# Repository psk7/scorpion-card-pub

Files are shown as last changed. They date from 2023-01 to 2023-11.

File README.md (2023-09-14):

## Контроллер периферии для ретро-компьютера Scorpion ZS-256

## Ревизия B:

Подключается к разъему периферии платы компьютера. Позволяет использовать USB клавиатуры, мыши, джойстики, геймпады.



## Ревизия С:
                 
Автономный контроллер USB клавиатуры и геймпада. Не привязан к разъему Scorpion и может
быть использован с любым Spectrum совместимым компьютером, использующим стандартную ZX клавиатуру, но
не имеет поддержки Kempston Mouse и возможностей, обеспечиваемых периферийным разъемом ZS-Scorpion за исключением
клавиатуры и Kempston джойстика.



## Уже реализовано:
- USB-хост: поддержка клавиатур, HID мышей, HID джойстиков/геймпадов, USB хабов
- USB-устройство: подключается к PC, возможно взаимодействие PC со Spectrum
- Безвейтовая ZX-клавиатура с произвольными раскладками, настраиваемыми с PC 
- Reset, Magic с клавиатуры
- Настраиваемые раскладки USB джойстика/геймпада, возможно задействование до 16 кнопок 
- Регенерация синхросмеси. Никаких больше перемычек/разрезов на плате. PAL кодер теперь дает нормальный цветной сигнал
- С доп. платой (в слот шины) USB мышь превращается в Kempston mouse
- Транзитом передает на гребенки: RGB сигнал (с выбором джампером оригинальная/регенерированная синхросмесь), стерео-аудио, моно-аудио, оригинальный видео сигнал, магнитофонный вход/выход, RS-232
- Единая точка подключения питания
- Подключение внешнего джойстика (от Spectrum)
- Настраиваемое отображение кнопок USB джойстика на кнопки ZX клавиатуры/Kempston Joystick
- Управление/индикация на клавиатуре турбой через двухпиновую колодку скорпиона
- Захват centronix в передача на PC
- Проигрыватель tap/tzx с PC через USB порт в Спектрум (`LOAD ""`)
- Транзитная передача с RS232 Скорпиона 
- Поддержка нескольких джойстиков/геймпадов

### Планируется:
- Настройки контроллера (раскладки, мышь, джойстик) через доп. плату нативным приложением для скорпиона

### Недостатки: :smile:
- Нет поддержки PS/2 мышей и клавиатур

## Ревизия А: (Устаревшая)

ВНИМАНИЕ!!! Эта ревизия НЕ РЕКОМЕНДУЕТСЯ К ИЗГОТОВЛЕНИЮ. К сожалению, при проектировании был выбран микроконтроллер не позволяющий реализовать все желаемое по причине нехватки ОЗУ. Готовится к публикации ревизия B, в которой эта проблема устранена.

Файлы для производства удалены из репозитория.

## Содержимое репозитория:
### revB
- cpld - Прошивки микросхем EPM3064
- gerbers - Файлы для производства плат

### revC
- kbd - Прошивка клавиатурной матрицы
- kicad - Проект плат
- atmega - Прошивка управляющего контроллера

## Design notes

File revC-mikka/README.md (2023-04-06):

## Специальная редакция контроллера клавиатуры ревизии C для Mikka_A

Ревизия C не предполагает поддержки мыши. Однако, по просьбе Mikka_A такая поддержка была добавлена.

Для соединения с платой портов мыши был позаимствован сервисный разъем для программирования микроконтроллера. 

В этой ревизии в FUSE установлен бит RSTDISBL, что исключат возможность программирования
микроконтроллера в устройстве. Программирование возможно только в высоковольтном параллельном режиме.

Также, полностью переработан подход к соответствию кнопок PC клавиатуры и ZX клавиатуры.

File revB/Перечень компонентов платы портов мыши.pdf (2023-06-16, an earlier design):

Номер | Корпус | Кол-во | Номинал | Примечание
C1 | C_0805_2012Metric | 1 10nF
C2 | C_Radial_D6.3mm_ H11.0mm_P2.50mm | 1 100uF
C3,C6,C4,C5 | C_0805_2012Metric | 4 0.1uF
J1 | PinHeader_2x05_P2.54mm | 1 | | JTAG
J2 | PinHeader_1x02_P2.54mm | 1 | | Не устанавливать
J3 | IDC-Header_2x04_P2.54mm | 1 EXT | | К контроллеру
R2,R1 | R_0805_2012Metric | 2 10k | | R1 можно не устанавливать
R3 | R_0805_2012Metric | 1 0
U1 | TQFP-44_10x10mm_P0.8mm | 1 EPM3064
U2 | SOT-89-3 | 1 L78L33

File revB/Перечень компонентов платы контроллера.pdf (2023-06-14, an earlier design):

Номер | Корпус | Кол-во | Номинал | Примечание
C13 | CP_Elec_6.3x7.7 | 1 220uF | | Любой подходящий SMD электролит или SMD тантал емкостью 200-1000мкф
C16 | Radial_D6.3mm_H11.0mm_P2.50m m | 1 200uF | | Любой подходящий выводной емкостью 200-1000мкф
C18,C4,C12 | C_0805_2012Metric | 3 4.7uF
C2,C1,C34,C33 | C_0805_2012Metric | 4 10p
C23 | C_0805_2012Metric | 1 10uF
C31,C6,C25,C24 | CP_EIA-3528-12_Kemet-T | 4 100uF
C35 | C_0805_2012Metric | 1 1uF
C36 | C_0805_2012Metric | 1 - | | Не устанавливать
C5,C11,C15,C21, C14,C10,C17, C26,C30,C3,C9,C 7,C8,C19 | C_0805_2012Metric | 14 0.1uF
D1 | LED_0805_2012Metric | 1
J1 | usb_mini | 1
J10,J5 | PinHeader_1x04_P2.54mm | 2
J11 | IDC-Header_2x04_P2.54mm | 1
J13 | PinHeader_2x03_P2.54mm | 1
J14 | PinHeader_1x02_P2.54mm | 1
J15 | PinHeader_2x05_P2.54mm | 1
J16 | ATX-4x4 | 1
J18 | PinHeader_1x04_P2.54mm | 1
J2 | PinHeader_1x03_P2.54mm | 1
J20 | PinHeader_1x02_P2.54mm | 1
J21 | PinHeader_1x02_P2.54mm | 1
J3 | PinHeader_2x05_P2.54mm | 1
J4,J7,J6 | PinHeader_1x02_P2.54mm | 3
J8 | PinHeader_1x07_P2.54mm | 1
J9 | PinHeader_1x03_P2.54mm | 1
R11 | R_0805_2012Metric | 1 1K
R13 | R_0805_2012Metric | 1 0
R14 | R_0805_2012Metric | 1 2k
R2,R1 | R_0805_2012Metric | 2 33
R3 | R_0805_2012Metric | 1 1k5
R5 | R_0805_2012Metric | 1 10k
R7 | R_0805_2012Metric | 1 1k
R8 | R_0805_2012Metric | 1 1k2
R9 | R_0805_2012Metric | 1 250
RN3,RN2,RN1 | RESCAF80P320X160X60-8N | 3 4x1k2
U1 | LQFP-64_10x10mm_P0.5mm | 1 STM32F103R8
U10 | SOT-223-3_TabPin2 | 1 LD1117S33TR
U11 | SOT-363_SC-70-6 | 1 TS5A3159DCK
U2 | TQFP-44_10x10mm_P0.8mm | 1 EPM3064
U3 | LQFP-32_5x5mm_P0.5mm | 1 MAX3421EEHJ+T
U4 | TSOP-6_1.65x3.05mm_P0.95mm | 1 IP4220CZ6
U5 | SOIC-8_3.9x4.9mm_P1.27mm | 1 25LC256T
U9 | SOT65P210X110-6N | 1 SMF05CT1G
Y2,Y1 | SMD_3225-4Pin_3.2x2.5mm | 2 12MHz

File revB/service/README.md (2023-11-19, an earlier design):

Программа сервисного обслуживания контроллера 

- Редактирование пользовательских раскладок клавиатуры
- Проигрыватель образов ленты TAP/TZX
- Резервное копирование/восстановление/сброс настроек контроллера
- Обновление встроенного ПО контроллера (firmware)

Версии
- SFNET-1 - Начальная версия
- SFNET-2 - Исправлены некоторые ошибки, возникающие при записи макроса

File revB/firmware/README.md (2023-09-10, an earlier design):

 - fw-1.bin, fw-1.hex - Первоначальная версия (10.09.2023)

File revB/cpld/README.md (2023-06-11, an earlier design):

- epm3064-main - Прошивка микросхемы EPM3064 контроллера клавиатуры
- epm3064-ext - Прошивка микросхемы EPM3064 дополнительной платы портов Kempston мыши

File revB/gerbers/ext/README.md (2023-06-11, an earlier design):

Производственные файлы для дополнительной платы портов Kempston мыши

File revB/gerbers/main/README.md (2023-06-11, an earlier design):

Производственные файлы для основной платы контроллера



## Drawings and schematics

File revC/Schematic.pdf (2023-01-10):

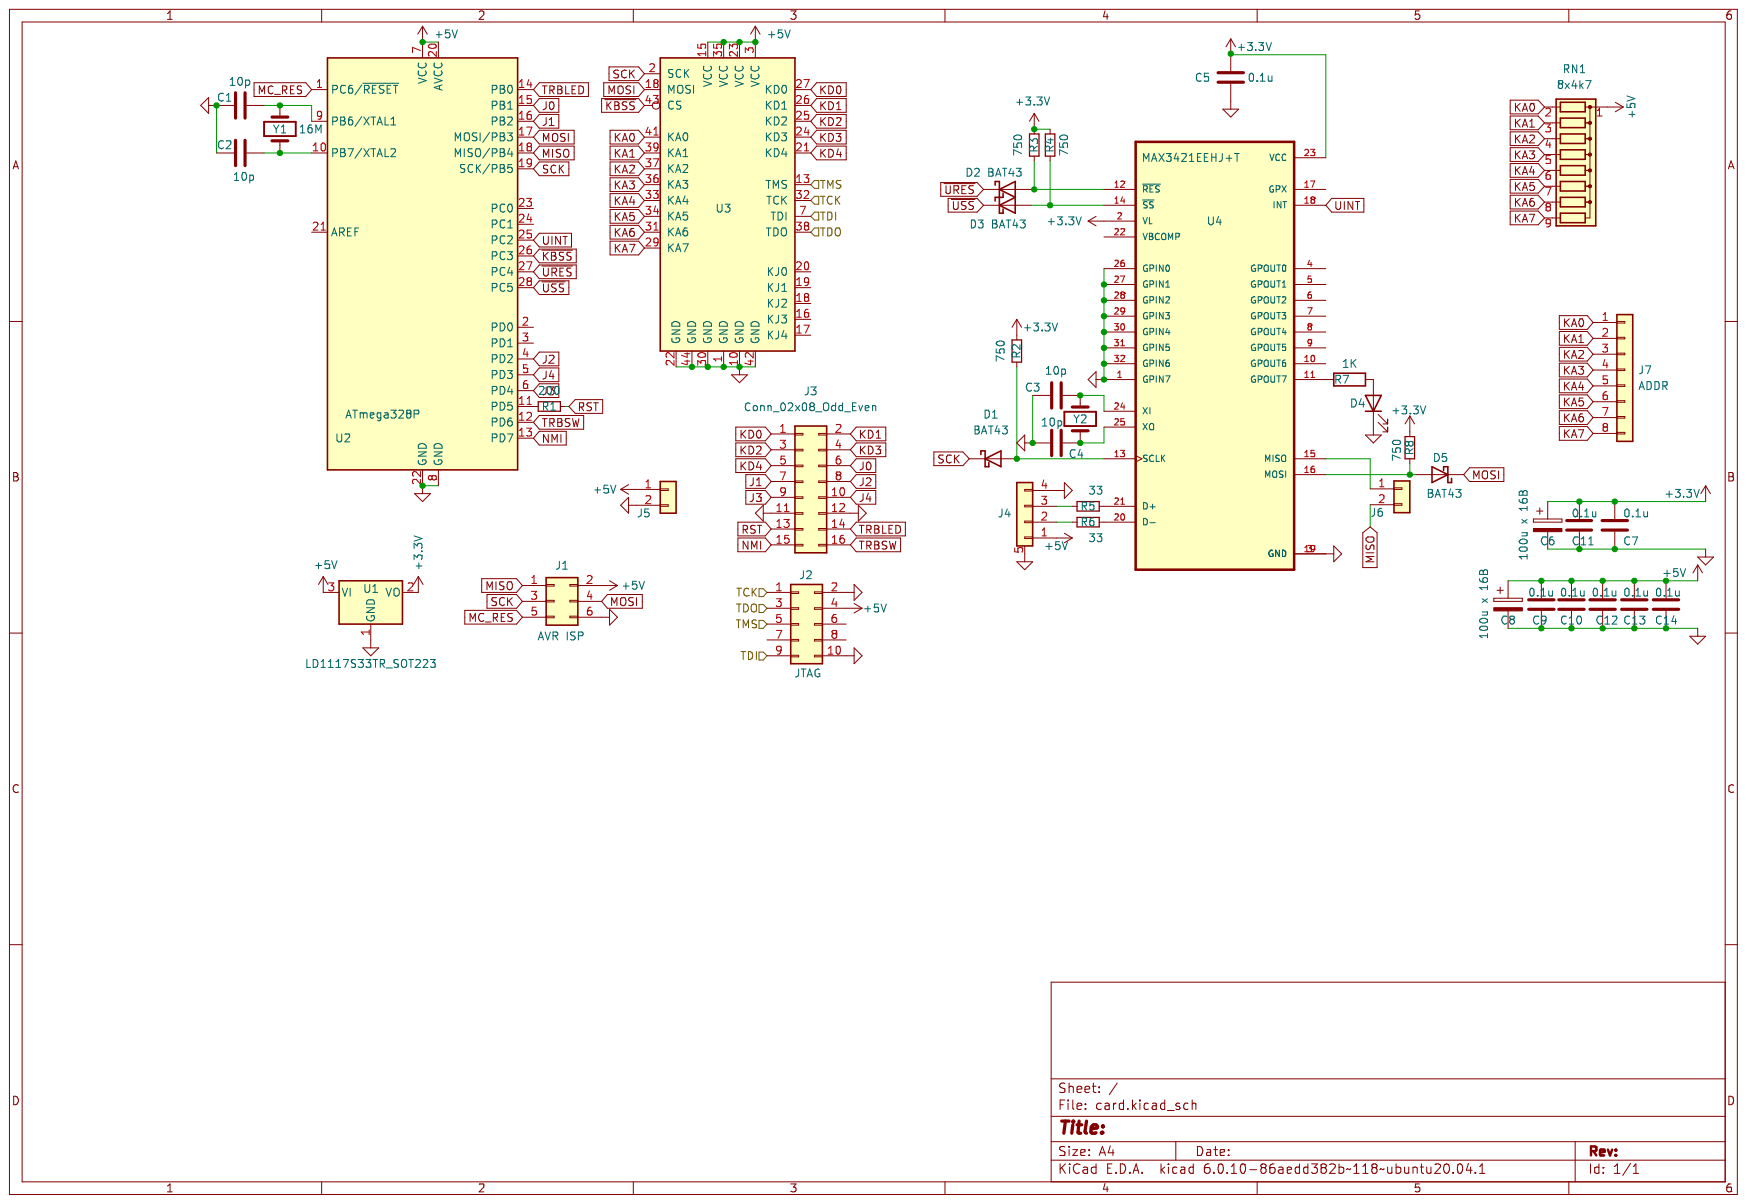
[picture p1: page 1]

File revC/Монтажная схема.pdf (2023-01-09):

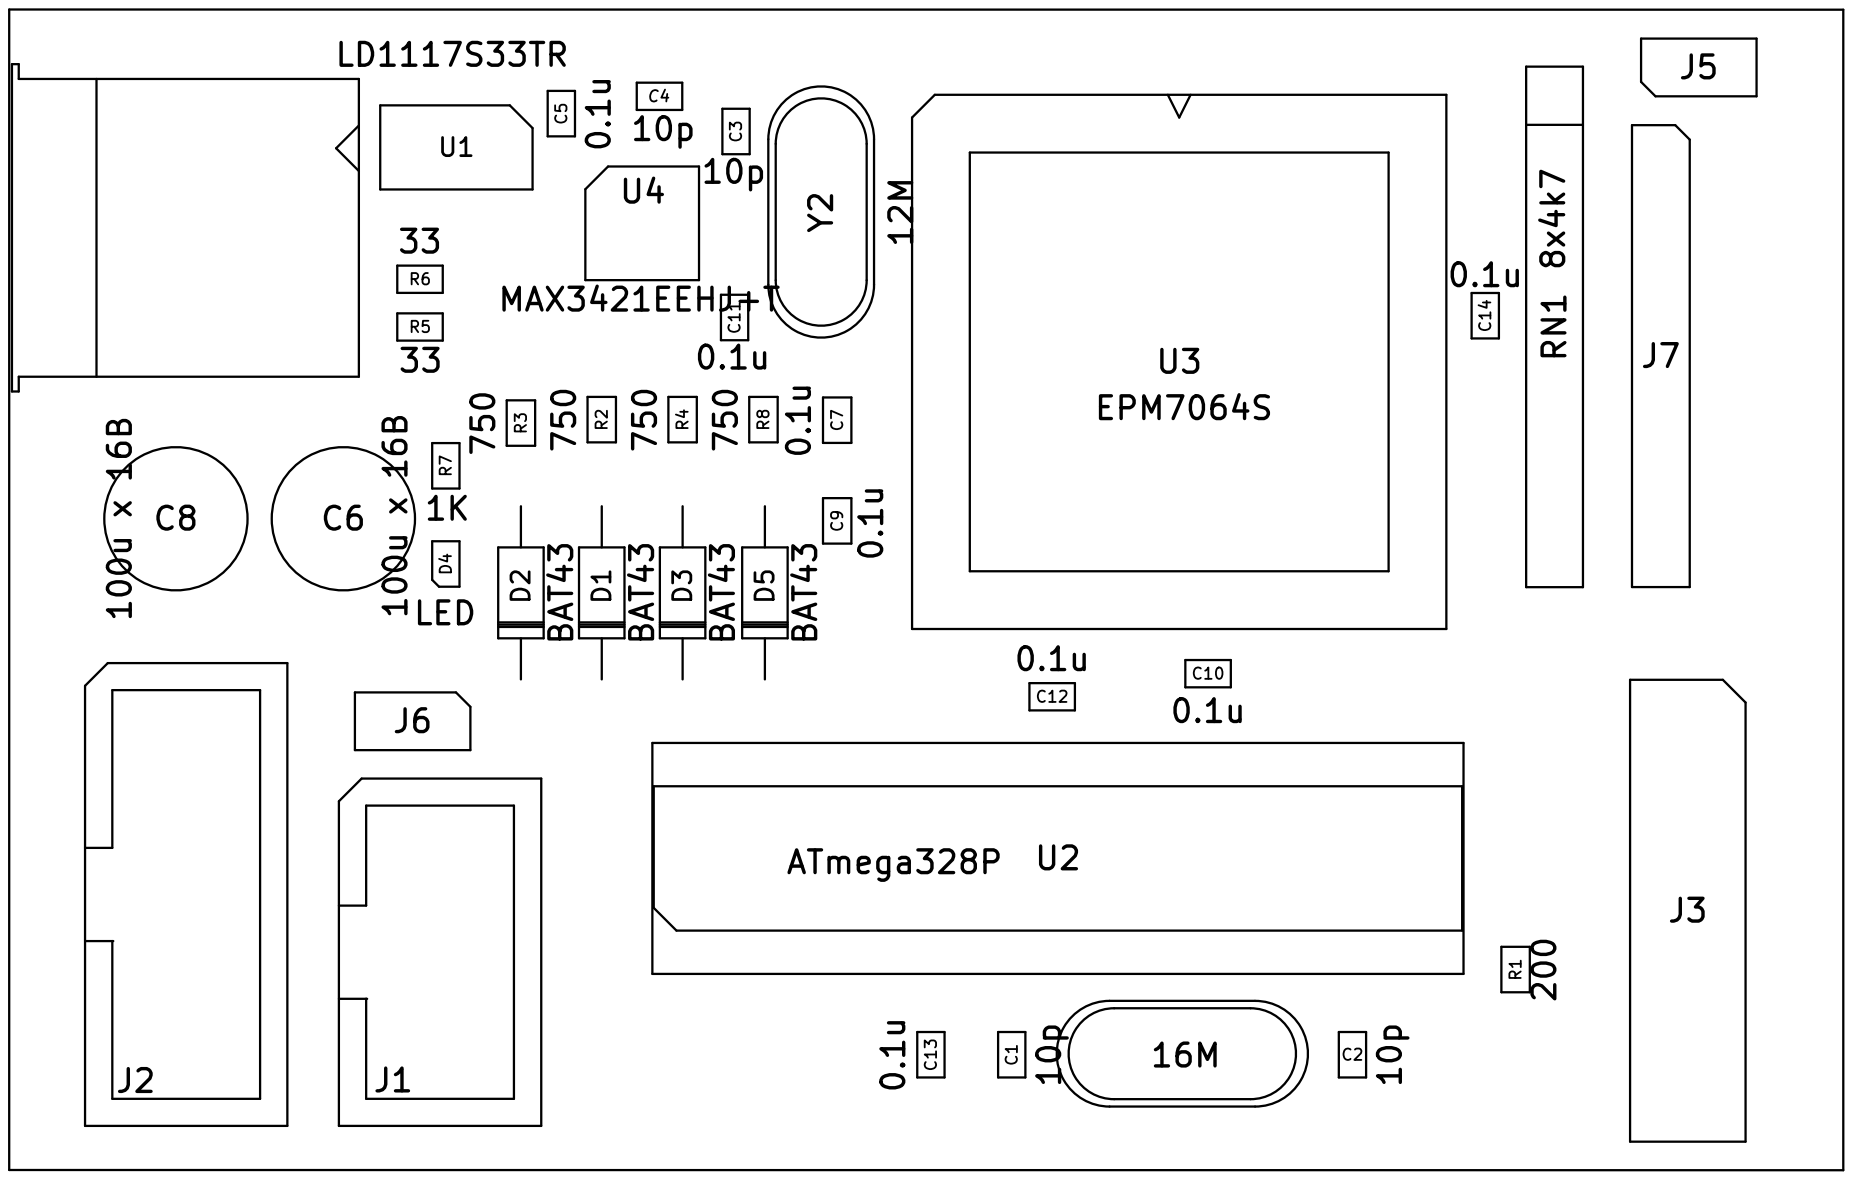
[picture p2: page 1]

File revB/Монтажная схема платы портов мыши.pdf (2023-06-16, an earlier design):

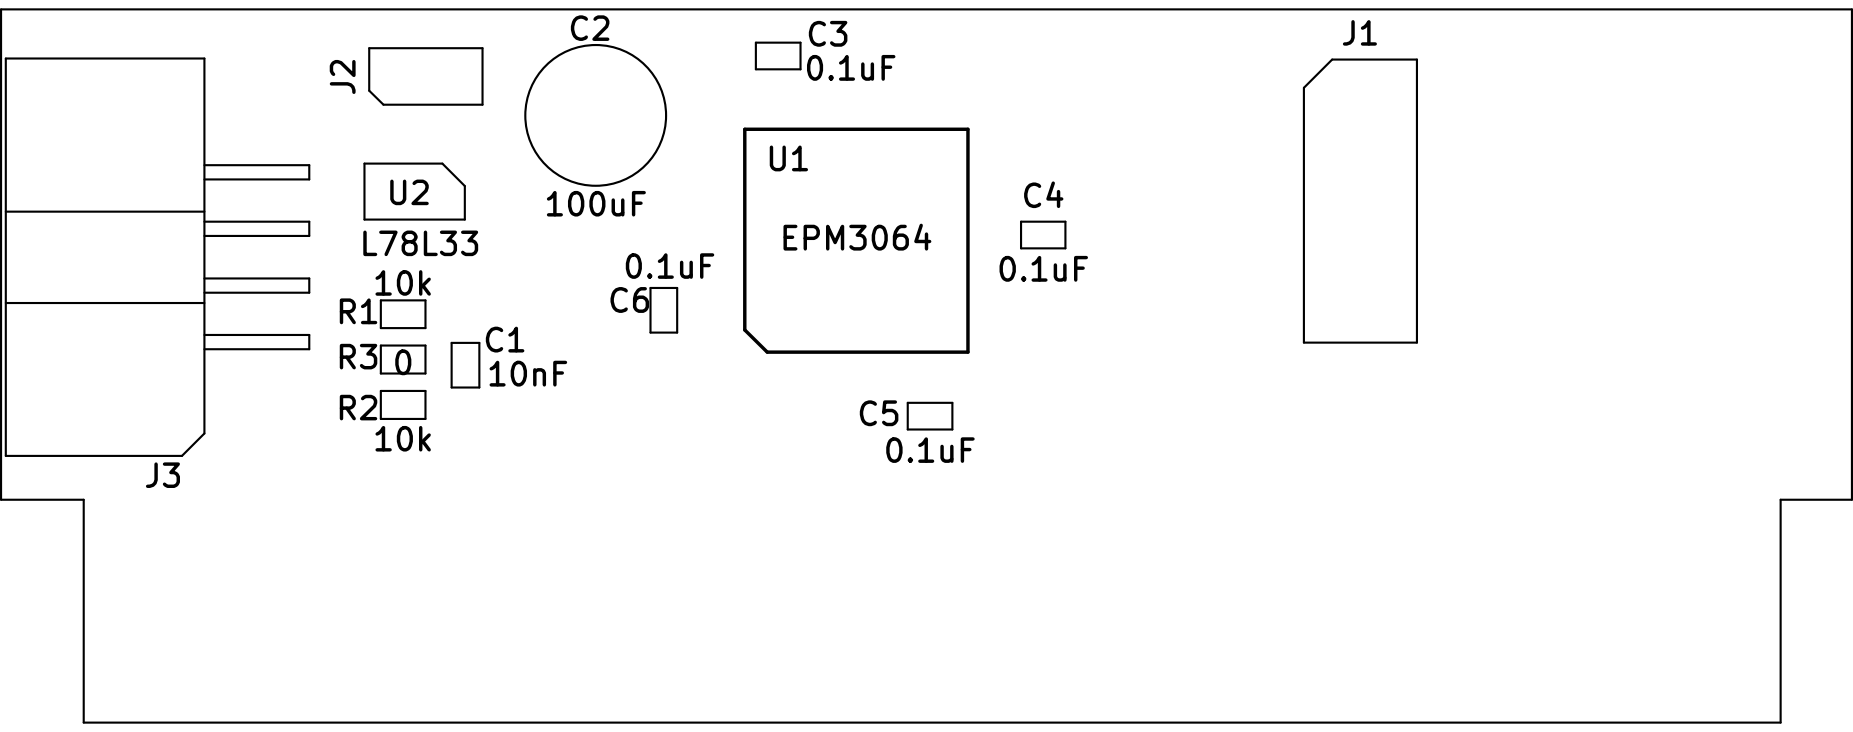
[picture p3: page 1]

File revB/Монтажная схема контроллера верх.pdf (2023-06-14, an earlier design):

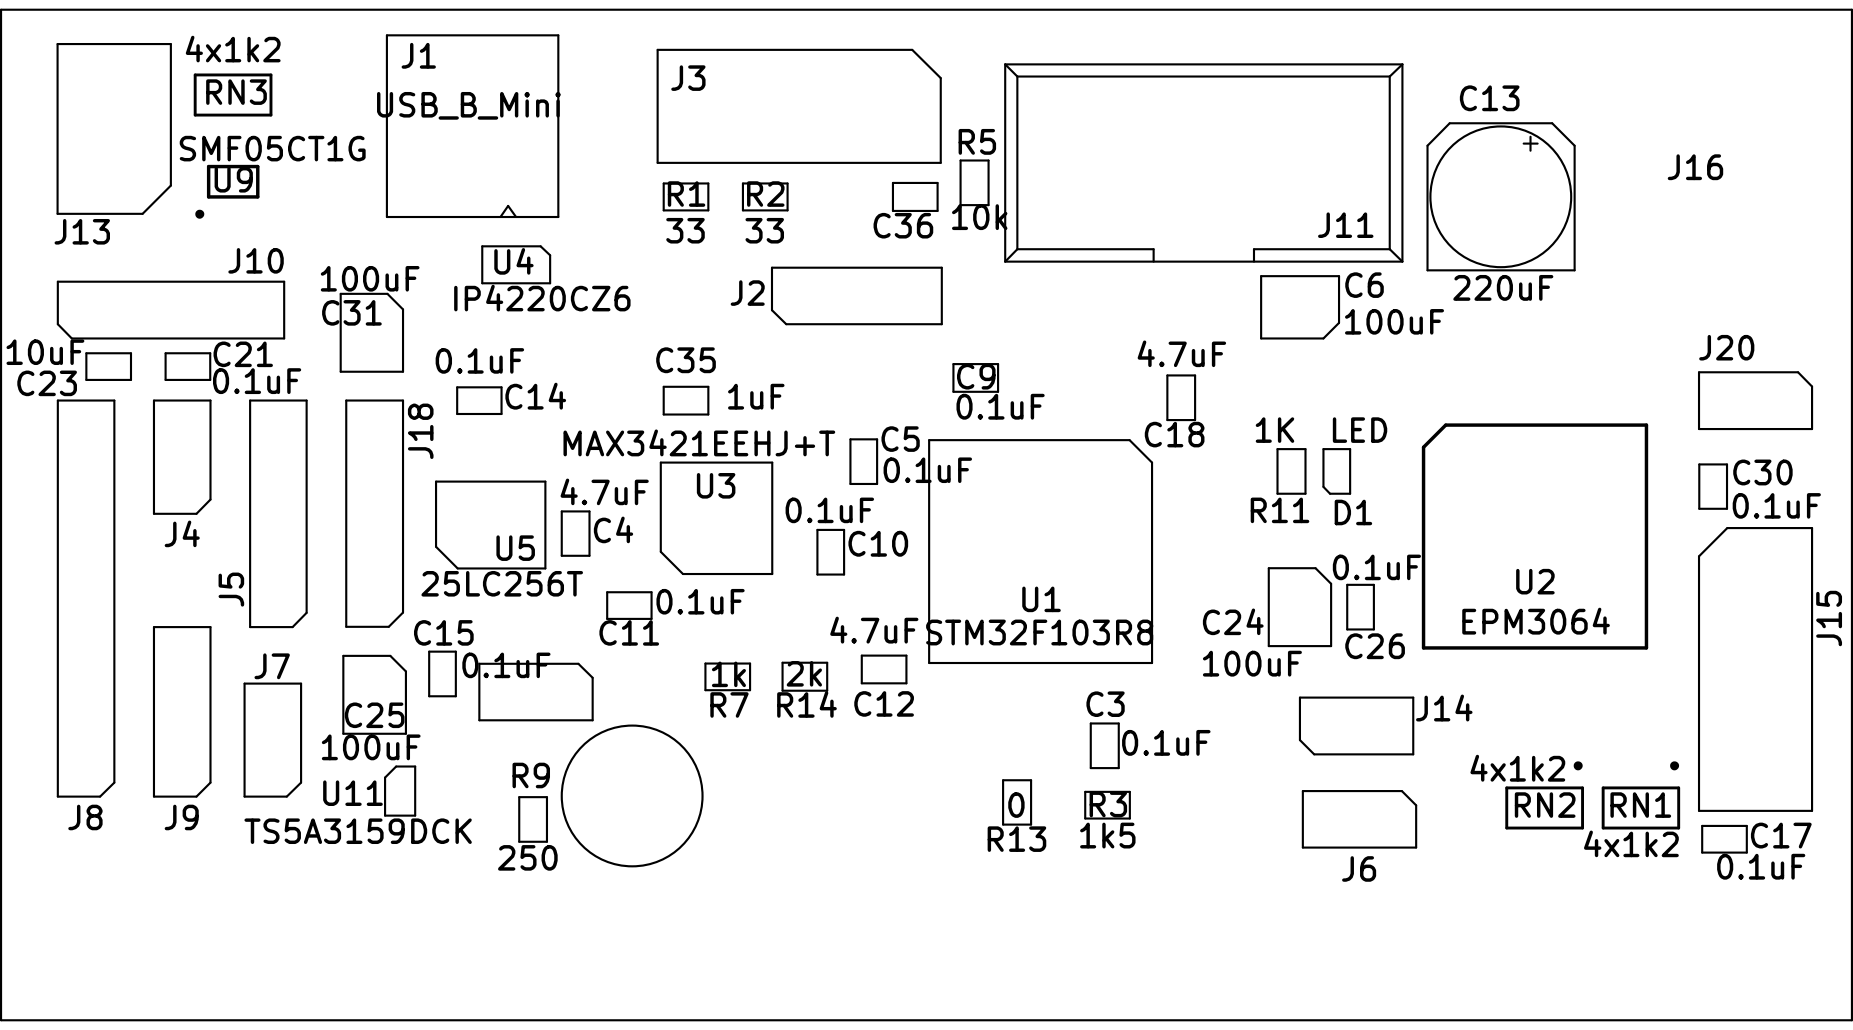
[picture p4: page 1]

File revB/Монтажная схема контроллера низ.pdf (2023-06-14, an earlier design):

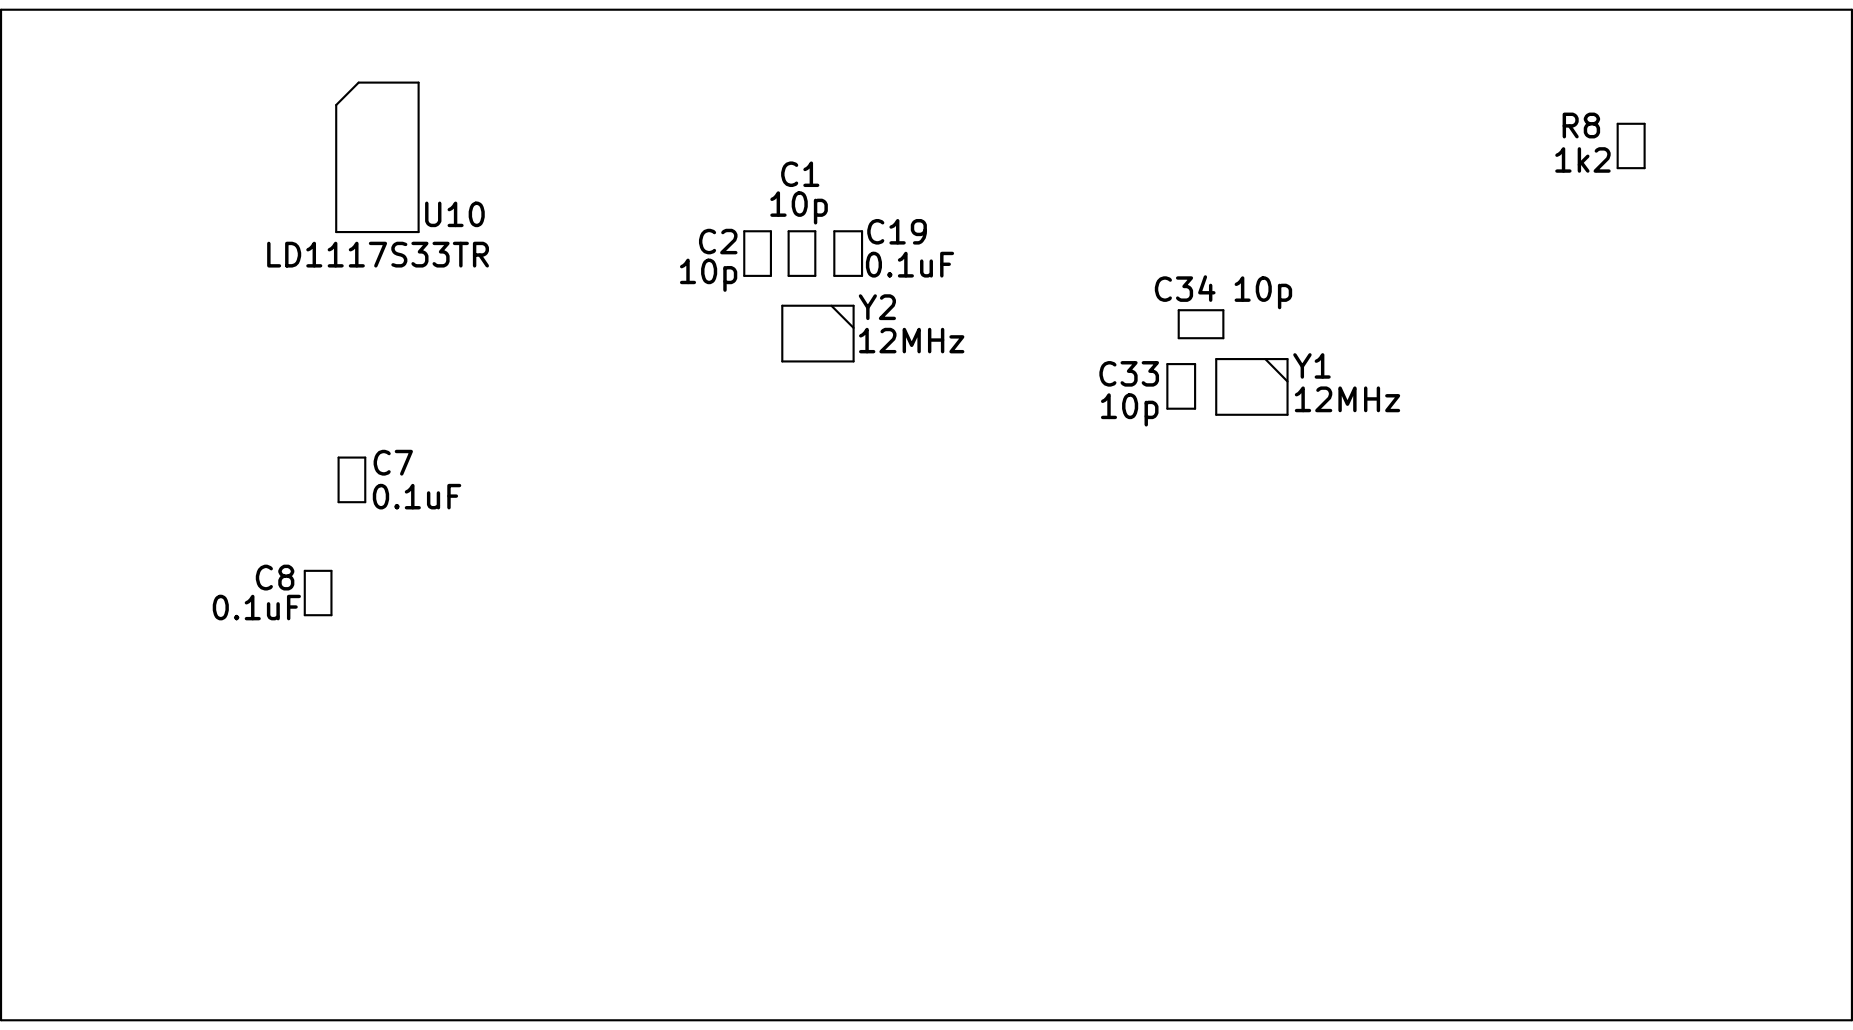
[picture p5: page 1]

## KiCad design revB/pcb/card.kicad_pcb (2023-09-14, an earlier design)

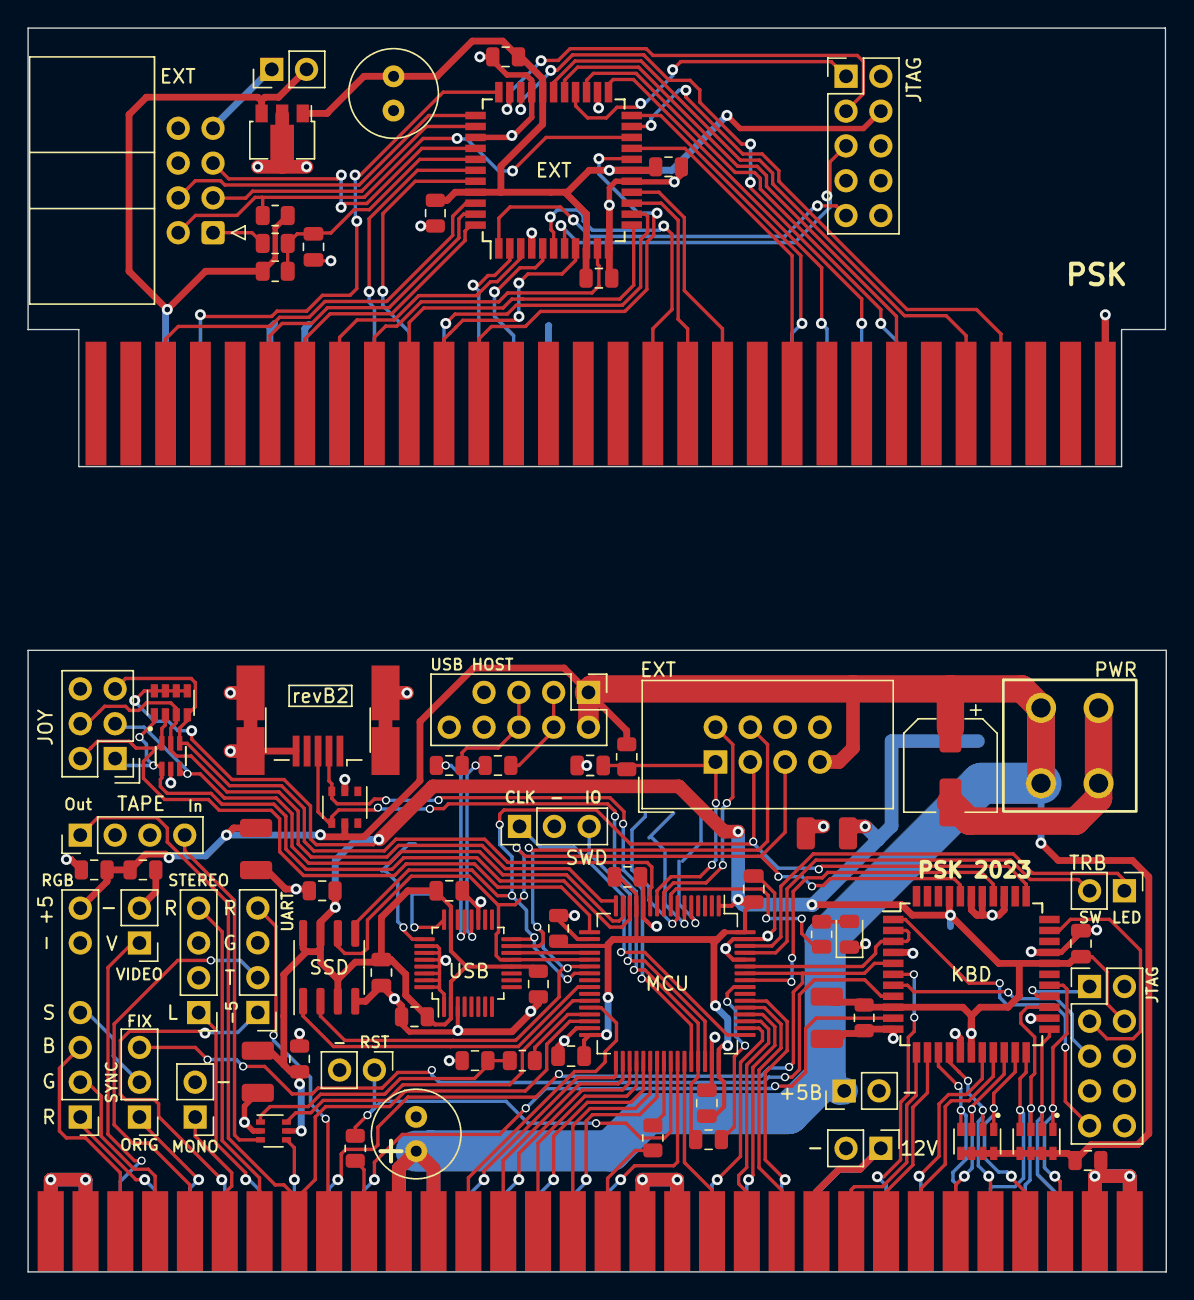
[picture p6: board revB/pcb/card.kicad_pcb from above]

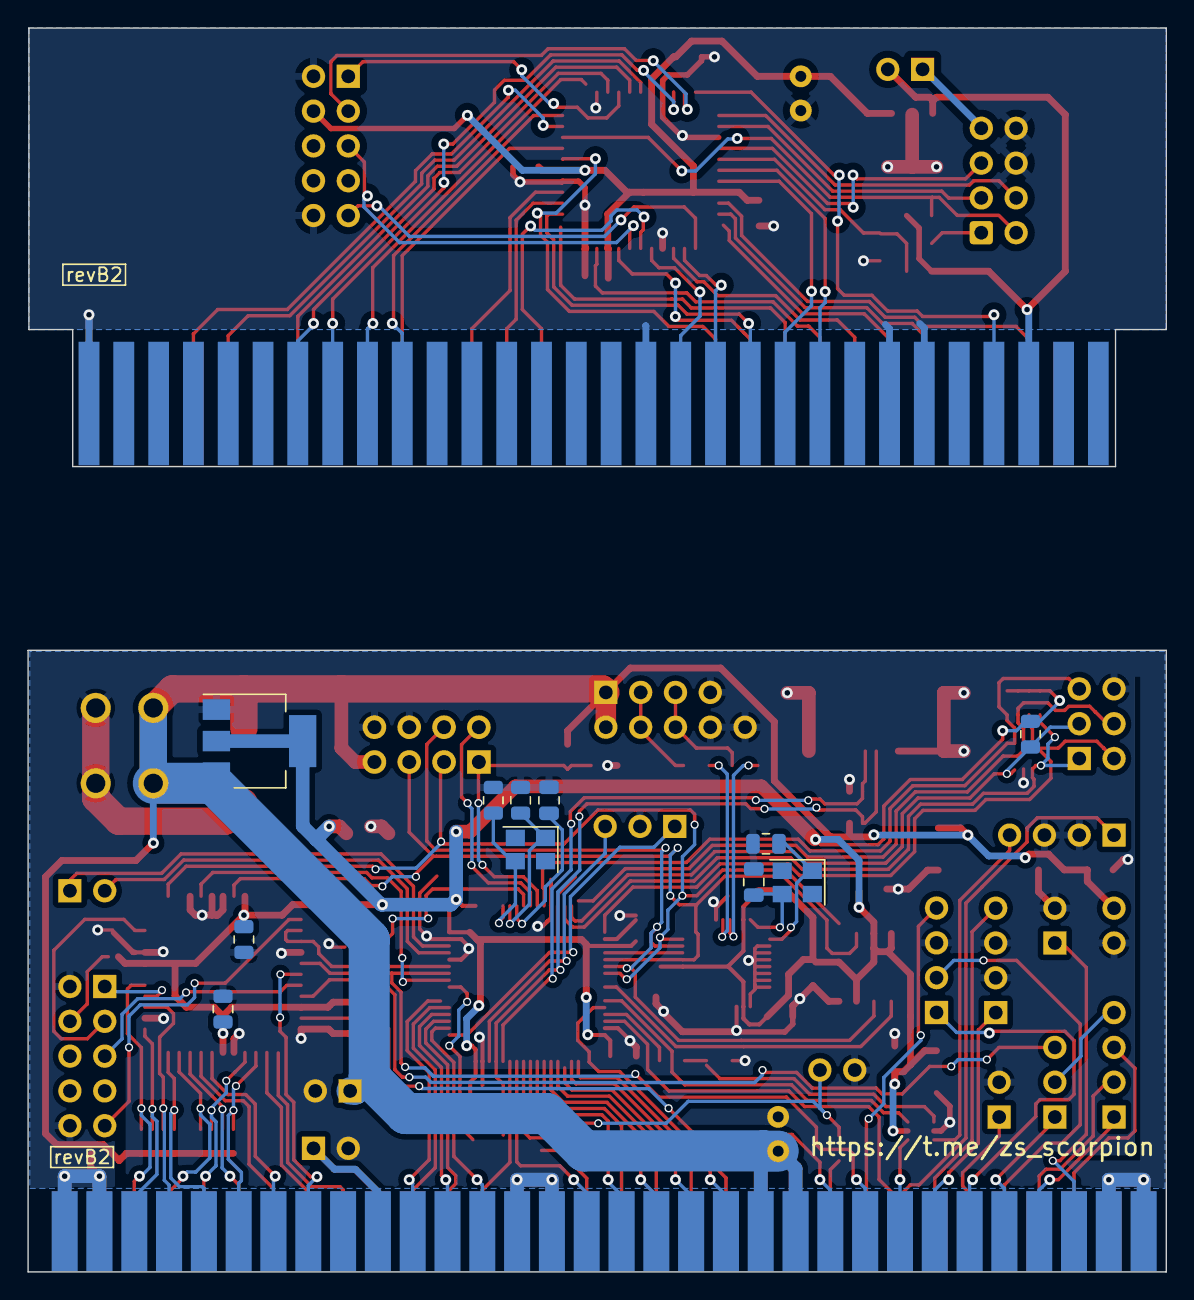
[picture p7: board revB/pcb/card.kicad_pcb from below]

Board: 2 copper layers, 83.1 x 45.4 mm, 88 parts (11 on the bottom side), 130 nets.

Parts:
C1, C2, C33, C34: 9p; C_0805_2012Metric
C3, C5, C7, C8, C9, C10, C11, C14, C15, C17, C21, C22, C23, C26, C27, C28, C29, C30, C32, C35, C36: C; C_0805_2012Metric
C4, C12, C18: 4.7uF; C_0805_2012Metric
C6, C24, C25, C31: CP; CP_EIA-3528-12_Kemet-T
C13: CP; CP_Elec_6.3x7.7
C16, C20: CP; C_Radial_D6.3mm_H11.0mm_P2.50mm
C19: 0.1uF; C_0805_2012Metric
D1: LED; LED_0805_2012Metric
J1: USB_B_Mini; usb_mini
J2: SWD; PinHeader_1x03_P2.54mm_Vertical
J3: Conn_01x04; PinHeader_2x05_P2.54mm_Vertical
J4, J6, J7: Conn_01x02; PinHeader_1x02_P2.54mm_Vertical
J5, J10: Conn_01x04; PinHeader_1x04_P2.54mm_Vertical
J8: Conn_01x07_RGB; PinHeader_1x07_P2.54mm_Vertical_RGB
J9: Conn_01x03; PinHeader_1x03_P2.54mm_Vertical
J11: Conn_01x08; IDC-Header_2x04_P2.54mm_Vertical
J12, J15: JTAG; PinHeader_2x05_P2.54mm_Vertical
J13: Conn_02x03_Odd_Even; PinHeader_2x03_P2.54mm_Vertical
J14, J19: +5В; PinHeader_1x02_P2.54mm_Vertical
J16: PWR; pwr
J17: EXT; IDC-Header_2x04_P2.54mm_Horizontal
J18: UART; PinHeader_1x04_P2.54mm_Vertical
J20: 3V3; PinHeader_1x02_P2.54mm_Vertical
J21: Conn_01x01_Male; PinHeader_1x02_P2.54mm_Vertical
R1, R2: 33; R_0805_2012Metric
R3: 1k5; R_0805_2012Metric
R4, R7: 0; R_0805_2012Metric
R5, R11: 1K; R_0805_2012Metric
R6, R12: 1k; R_0805_2012Metric
R8: 1k2; R_0805_2012Metric
R9, R13: 250; R_0805_2012Metric
R14: -; R_0805_2012Metric
RN1, RN2, RN3: 4x1k2; RESCAF80P320X160X60-8N
U1: STM32F103R8; LQFP-64_10x10mm_P0.5mm
U2: EPM3064; TQFP-44_10x10mm_P0.8mm
U3: MAX3421EEHJ+T; LQFP-32_5x5mm_P0.5mm
U4: IP4220CZ6; TSOP-6_1.65x3.05mm_P0.95mm
U5: 25LC256T; SOIC-8_3.9x4.9mm_P1.27mm
U7: EXT; TQFP-44_10x10mm_P0.8mm
U8: L78L33; SOT-89-3
U9: SMF05CT1G; SOT65P210X110-6N
U10: LD1117S33TR; SOT-223-3_TabPin2
U11: TS5A3159DCK; SOT-363_SC-70-6
X1: ScorpionEdgeConnector; PADS_2.5_32
X2: ScorpionBusConnector; PADS_2.5_32
Y1, Y2: 12MHz; Crystal_SMD_3225-4Pin_3.2x2.5mm

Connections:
+3.3V: C20.1, C22.1, C27.1, C28.1, C29.1, J12.4, U7.9 (VCC), U7.17 (VCC), U7.29 (VCC), U7.41 (VCC), U8.1 (OUT)
+3V3: C3.1, C4.1, C5.1, C6.1, C7.1, C8.1, C9.1, C10.1, C11.1, C12.1, C14.1, C15.1, C18.1, C24.1, C25.1, C26.1, C30.1, C35.1, J15.4, R8.1, RN3.5, RN3.6, RN3.7, RN3.8, U1.1 (VBAT), U1.13 (VDDA), U1.19 (VDD), U1.32 (VDD), U1.48 (VDD), U1.64 (VDD), U2.9 (VCC), U2.17 (VCC), U2.29 (VCC), U2.41 (VCC), U3.2 (VL), U3.12 (~RES), U3.23 (VCC), U5.3 (~WP), U5.7 (~HOLD), U5.8 (VCC), U10.2 (VO), U11.5 (V+)
+5V: C13.1, C16.1, C17.1, C21.1, C23.1, C31.1, J3.1, J3.6, J8.7, J11.7, J14.1, J16.1, J16.2, J19.2, R5.2, R6.1, R12.1, RN1.5, RN1.6, RN1.7, RN1.8, RN2.5, RN2.6, RN2.7, RN2.8, U4.5 (Vbus), U8.3 (IN), U10.3 (VI), X1.21 (+5V), X1.22 (+5V), X1.23 (+5V), X1.24 (+5V), X2.6 (+5V)
+12V: J6.1, X1.45 (+12V), X1.46 (+12V)
-5V: J18.1, X1.12 (+5V)
/ExtCard/TCK: J12.1, U7.26 (TCK)
/ExtCard/TDI: J12.9, U7.1 (TDI)
/ExtCard/TDO: J12.3, U7.32 (TDO)
/ExtCard/TMS: J12.5, U7.7 (TMS)
/LED2: R11.2, U1.8 (PC0)
/MAGIC: R13.1, U1.40 (PC9)
/STGSS: U1.25 (PC5), U5.1 (~CS)
/SWDCLK: J2.1, U1.49 (PA14)
/SWDIO: J2.3, U1.46 (PA13)
/TCK: J15.1, U2.26 (TCK)
/TDI: J15.9, U2.1 (TDI)
/TDO: J15.3, U2.32 (TDO)
/TMS: J15.5, U2.7 (TMS)
/USBC_DM: J1.2 (D-), U1.44 (PA11), U4.3 (D-)
/USBC_DP: J1.3 (D+), R3.2, U1.45 (PA12), U4.4 (D+)
/USBH_DM: J3.2, J3.7, R2.2
/USBH_DP: J3.3, J3.8, R1.2
/USB_PULLUP: R3.1, U1.56 (PB4)
/USS: U1.20 (PA4), U3.14 (~SS)
A0: U7.39 (A0), X2.18 (A0)
A1: U7.40 (A1), X2.20 (A1)
A2: U7.13 (A2), X2.22 (A2)
A3: U7.2 (A3), X2.24 (A3)
A4: U7.25 (A4), X2.48 (A4)
A5: U7.31 (A5), X2.46 (A5)
A6: U7.23 (A6), X2.44 (A6)
A7: U7.22 (A7), X2.42 (A7)
A8: U7.28 (A8), X2.51 (A8)
A10: U7.21 (A10), X2.53 (A10)
B: J8.3, X1.5 (B)
CC: U1.58 (PB6), U2.5 (KC), X1.18 ((CC))
CN0: U1.36 (PB15), X1.29 (Centr_0)
CN1: U1.39 (PC8), X1.32 (Centr_1)
CN2: U1.38 (PC7), X1.31 (Centr_2)
CN3: U1.34 (PB13), X1.27 (Centr_3)
CN4: U1.28 (PB2), X1.25 (Centr_4)
CN5: U1.37 (PC6), X1.30 (Centr_5)
CN6: U1.33 (PB12), X1.26 (Centr_6)
CN7: U1.35 (PB14), X1.28 (Centr_7)
CNBUSY: U1.43 (PA10), X1.39 (BUSY)
CNSTB: U1.42 (PA9), X1.34 (Strobe)
D0: U7.43 (D0), X2.11 (D0)
D1: U7.44 (D1), X2.13 (D1)
D2: U7.3 (D2), X2.15 (D2)
D3: U7.8 (D3), X2.21 (D3)
D4: U7.18 (D4), X2.23 (D4)
D5: U7.12 (D5), X2.19 (D5)
D6: U7.10 (D6), X2.17 (D6)
D7: U7.42 (D7), X2.5 (D7)
DELAY_IN: U1.59 (PB7), U2.2 (DELAY_IN2), U2.3 (DELAY_IN)
DOS: U7.33 (DOS), X2.8 (DOS)
DSR: J18.4, X1.17 (DSR)
EINT: J11.2, U1.9 (PC1)
EINT_E: J17.2, R12.2, U7.20 (INT)
ESS: C36.2, J11.1, R5.1, U1.10 (PC2)
ESS_E: C32.2, R4.1, R6.2, U7.38 (SS)
G: J8.2, X1.7 (G)
GND: C1.2, C2.2, C3.2, C4.2, C5.2, C6.2, C7.2, C8.2, C9.2, C10.2, C11.2, C12.2, C13.2, C14.2, C15.2, C16.2, C17.2, C18.2, C19.2, C20.2, C21.2, C22.2, C23.2, C24.2, C25.2, C26.2, C27.2, C28.2, C29.2, C30.2, C31.2, C32.1, C33.2, C34.2, C35.2, C36.1, D1.1 (K), J1.5 (GND), J1.6 (Shield), J2.2, J3.4, J3.9, J3.10, J4.2, J5.2, J5.3, J6.2, J7.2, J8.6, J10.2, J10.3, J11.6, J11.8, J12.2, J12.10, J13.6, J14.2, J15.2, J15.10, J16.3, J16.4, J17.6, J17.8, J18.3, J21.2, R7.1, U1.12 (VSSA), U1.18 (VSS), U1.31 (VSS), U1.47 (VSS), U1.60 (BOOT0), U1.63 (VSS), U2.4 (GND), U2.11 (GND), U2.16 (GND), U2.24 (GND), U2.30 (GND), U2.36 (GND), U2.38 (UNUSED), U2.39 (UNUSED), U3.1 (GPIN7), U3.3 (GND), U3.19 (GND), U3.26 (GPIN0), U3.27 (GPIN1), U3.28 (GPIN2), U3.29 (GPIN3), U3.30 (GPIN4), U3.31 (GPIN5), U3.32 (GPIN6), U4.2 (GND), U5.4 (GND), U7.4 (GND), U7.11 (GND), U7.16 (GND), U7.24 (GND), U7.30 (GND), U7.36 (GND), U8.2 (GND), U9.2, U10.1 (GND), U11.2 (GND), X1.1 (GND), X1.2 (GND), X1.3 (GND), X1.4 (GND), X1.35 (GND), X1.36 (GND), X1.37 (GND), X1.38 (GND), X1.61 (GND), X1.62 (GND), X1.63 (GND), X1.64 (GND), X2.12 (GND), X2.14 (GND), X2.28 (GND), X2.59 (GND), X2.60 (GND)
IJ0: J13.1, RN3.1, U1.14 (PA0), U9.1
IJ1: J13.2, RN3.2, U1.17 (PA3), U9.6
IJ2: J13.3, R8.2, U1.15 (PA1), U9.3
IJ3: J13.4, RN3.3, U1.16 (PA2), U9.5
IJ4: J13.5, RN3.4, U1.11 (PC3), U9.4
IORQ: U7.6 (IORQ), X2.33 (IORQ)
IORQGE: U7.5 (IORQGE), X2.26 (IORQGE)
ITIN: J10.4, U11.3
J0: U1.51 (PC10), X1.41 (Kemps_0)
J1: U1.52 (PC11), X1.42 (Kemps_1)
J2: U1.54 (PD2), X1.44 (Kemps_2)
J3: U1.53 (PC12), X1.43 (Kemps_3)
J4: U1.50 (PA15), X1.40 (Kemps_4)
KA0: RN2.4, U2.14 (KA0), X1.54 (Kb_a8)
KA1: RN2.3, U2.20 (KA1), X1.53 (Kb_a9)
KA2: RN2.2, U2.15 (KA2), X1.55 (Kb_a10)
KA3: RN1.4, U2.22 (KA3), X1.56 (Kb_a11)
KA4: RN2.1, U2.21 (KA4), X1.57 (Kb_a12)
KA5: RN1.3, U2.25 (KA5), X1.58 (Kb_a13)
KA6: RN1.1, U2.27 (KA6), X1.59 (Kb_a14)
KA7: RN1.2, U2.23 (KA7), X1.60 (Kb_a15)
KBSS: U1.57 (PB5), U2.37 (SS)
KC: U2.10 (CC), X1.20 ((KC))
KD0: U2.19 (KD0), X1.51 (Kb_in0)
KD1: U2.18 (KD1), X1.52 (Kb_in1)
KD2: U2.13 (KD2), X1.49 (Kb_in2)
KD3: U2.6 (KD3), X1.50 (Kb_in3)
KD4: U2.12 (KD4), X1.47 (Kb_in4)
LEFT: J5.1, X1.14 (LEFT)
M1: U7.27 (M1), X2.47 (M1)
MC_RES: C19.1, U1.7 (NRST)
MISO: J11.4, U1.22 (PA6), U3.15 (MISO), U5.2 (MISO)
MISO5_E: J17.4, U7.34 (MISO)
MOSI: J11.3, U1.23 (PA7), U2.34 (DI), U3.16 (MOSI), U5.5 (MOSI)
MOSI5_E: J17.3, U7.35 (MOSI)
NMI: R13.2, X1.33 (MAGIC)
unnamed: D1.2 (A), R11.1
unnamed: J17.1, R4.2
unnamed: J17.7, J19.1
unnamed: J21.1, R9.2, U1.41 (PA8)
unnamed: R7.2, R14.1, U11.1
unnamed: R14.2, U1.29 (PB10)
unnamed: C2.1, U1.5 (PD0), Y2.3
unnamed: C1.1, U1.6 (PD1), Y2.1
unnamed: R1.1, U3.21 (D+)
unnamed: R2.1, U3.20 (D-)
unnamed: C33.1, U3.24 (XI), Y1.3
unnamed: C34.1, U3.25 (XO), Y1.1
OSYNC: J8.4, J9.2
OUT_SYNC: J9.3, U2.8 (OUT_SYNC)
R: J8.1, X1.8 (R)
RD: U7.14 (RD), X2.35 (RD)
RIGHT: J5.4, X1.13 (RIGHT)
SCK: J11.5, U1.21 (PA5), U2.40 (CLK), U3.13 (SCLK), U5.6 (SCK)
SCK5_E: J17.5, U7.37 (SCK)
SOUND: J7.1, X1.11 (SOUND)
SYNC: J9.1, X1.10 (SYNC)
TIN: U11.4, X1.16 (TAPE_IN)
TINC: U1.27 (PB1), U11.6
TOUT: J10.1, U1.30 (PB11), X1.15 (TAPE_OUT)
TRBLED: J20.1, U1.62 (PB9)
TRBSW: J20.2, U1.61 (PB8)
TXD: J18.2, X1.9 (TxD)
VIDEO: J4.1, X1.6 (VIDEO)
WAIT: U7.19 (WAIT), X2.41 (WAIT)
WR: U7.15 (WR), X2.37 (WR)
ZRES: R9.1, X1.19 (RESET)

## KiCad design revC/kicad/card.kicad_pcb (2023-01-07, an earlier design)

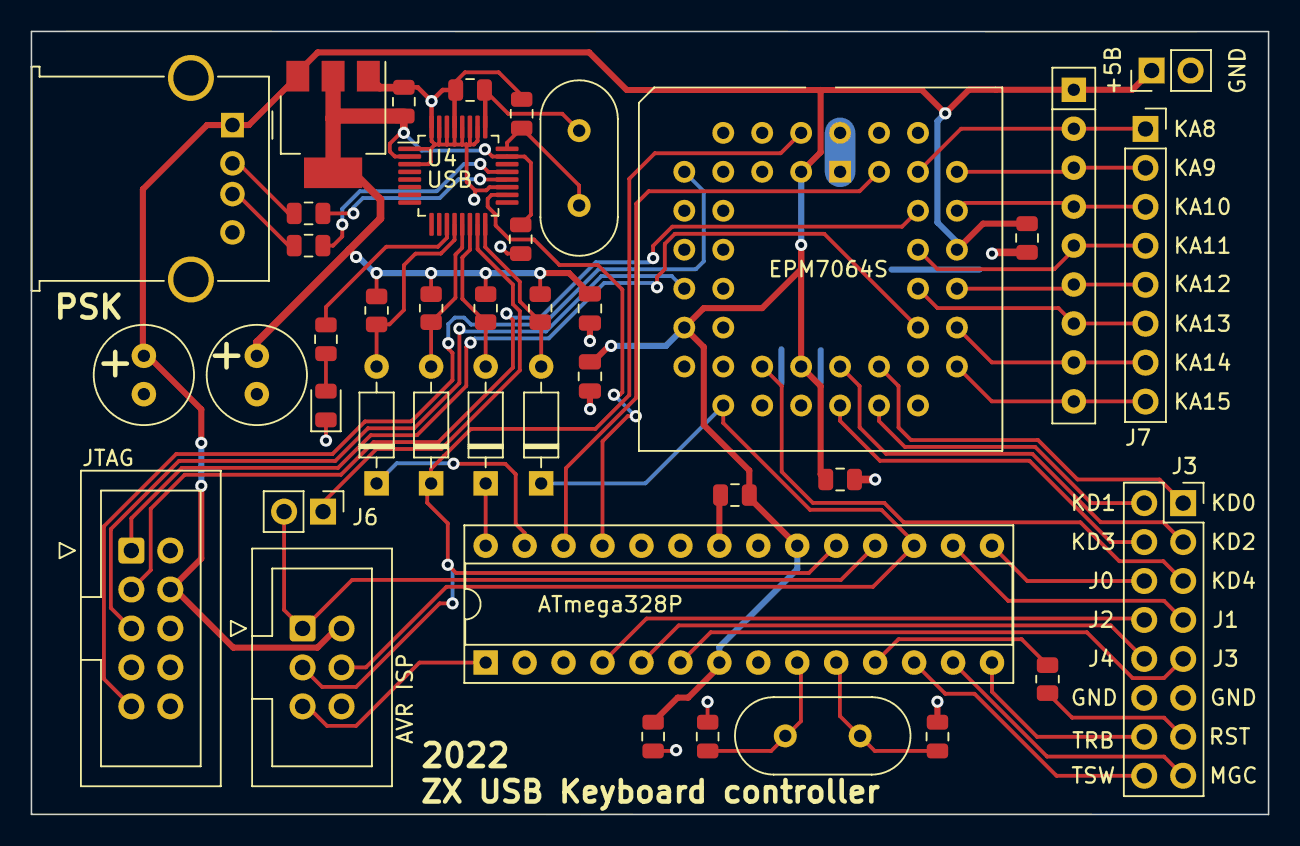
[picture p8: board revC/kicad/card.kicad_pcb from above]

Board: 2 copper layers, 80.7 x 51.1 mm, 41 parts (0 on the bottom side), 53 nets.

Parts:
C1, C2, C3, C4: 10p; C_0805_2012Metric
C5, C7, C9, C10, C11, C12, C13, C14: 0.1u; C_0805_2012Metric
C6, C8: 100u x 16В; C_Radial_D6.3mm_H11.0mm_P2.50mm
D1, D2, D3, D5: BAT43; D_DO-35_SOD27_P7.62mm_Horizontal
D4: LED; LED_0805_2012Metric
J1: AVR ISP; IDC-Header_2x03_P2.54mm_Vertical
J2: JTAG; IDC-Header_2x05_P2.54mm_Vertical
J3: Conn_02x08_Odd_Even; PinSocket_2x08_P2.54mm_Vertical
J4: Conn_01x04; USB_A_Molex_67643_Horizontal
J5: PWR; PinHeader_1x02_P2.54mm_Vertical
J6: PROG; PinHeader_1x02_P2.54mm_Vertical
J7: ADDR; PinSocket_1x08_P2.54mm_Vertical
R1: 200; R_0805_2012Metric
R2, R3, R4, R8: 750; R_0805_2012Metric
R5, R6: 33; R_0805_2012Metric
R7: 1K; R_0805_2012Metric
RN1: 8x4k7; R_Array_SIP9
U1: LD1117S33TR_SOT223; SOT-223-3_TabPin2
U2: ATmega328P; DIP-28_W7.62mm_Socket
U3: EPM7064S; PLCC-44_THT-Socket
U4: MAX3421EEHJ+T; LQFP-32_5x5mm_P0.5mm
Y1: 16M; Crystal_HC49-4H_Vertical
Y2: 12M; Crystal_HC49-4H_Vertical

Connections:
+3V3: C5.1, C6.1, C7.1, C11.1, R2.1, R3.1, R4.1, R8.1, U1.2 (VO), U4.2 (VL), U4.23 (VCC)
+5V: C8.1, C9.1, C10.1, C12.1, C13.1, C14.1, J1.2, J2.4, J4.1, J5.1, RN1.1 (common), U1.3 (VI), U2.7 (VCC), U2.20 (AVCC), U3.3 (VCC), U3.15 (VCC), U3.23 (VCC), U3.35 (VCC)
/TCK: J2.1, U3.32 (TCK)
/TDI: J2.9, U3.7 (TDI)
/TDO: J2.3, U3.38 (TDO)
/TMS: J2.5, U3.13 (TMS)
GND: C1.2, C2.2, C3.2, C4.2, C5.2, C6.2, C7.2, C8.2, C9.2, C10.2, C11.2, C12.2, C13.2, C14.2, D4.1 (K), J1.6, J2.2, J2.10, J3.11, J3.12, J4.4, J4.5 (Pin_4), J5.2, U1.1 (GND), U2.8 (GND), U2.22 (GND), U3.1 (GND), U3.10 (GND), U3.22 (GND), U3.30 (GND), U3.42 (GND), U3.44 (GND), U4.1 (GPIN7), U4.3 (GND), U4.19 (GND), U4.26 (GPIN0), U4.27 (GPIN1), U4.28 (GPIN2), U4.29 (GPIN3), U4.30 (GPIN4), U4.31 (GPIN5), U4.32 (GPIN6)
J0: J3.6, U2.15 (PB1)
J1: J3.7, U2.16 (PB2)
J2: J3.8, U2.4 (PD2)
J3: J3.9, U2.6 (PD4)
J4: J3.10, U2.5 (PD3)
KA0: J7.1, RN1.2 (R1), U3.41 (KA0)
KA1: J7.2, RN1.3 (R2), U3.39 (KA1)
KA2: J7.3, RN1.4 (R3), U3.37 (KA2)
KA3: J7.4, RN1.5 (R4), U3.36 (KA3)
KA4: J7.5, RN1.6 (R5), U3.33 (KA4)
KA5: J7.6, RN1.7 (R6), U3.34 (KA5)
KA6: J7.7, RN1.8 (R7), U3.31 (KA6)
KA7: J7.8, RN1.9 (R8), U3.29 (KA7)
KD0: J3.1, U3.27 (KD0)
KD1: J3.2, U3.26 (KD1)
KD2: J3.3, U3.25 (KD2)
KD3: J3.4, U3.24 (KD3)
KD4: J3.5, U3.21 (KD4)
MC_RES: J1.5, U2.1 (PC6/~RESET)
MISO: J1.1, J6.2, U2.18 (MISO/PB4)
MOSI: D5.1 (K), J1.4, U2.17 (MOSI/PB3), U3.18 (MOSI)
NMI: J3.15, U2.13 (PD7)
unnamed: C1.1, U2.9 (PB6/XTAL1), Y1.1
unnamed: C2.1, U2.10 (PB7/XTAL2), Y1.2
unnamed: C3.1, U4.24 (XI), Y2.1
unnamed: C4.1, U4.25 (XO), Y2.2
unnamed: D1.2 (A), R2.2, U4.13 (SCLK)
unnamed: D2.2 (A), R3.2, U4.12 (~RES)
unnamed: D3.2 (A), R4.2, U4.14 (~SS)
unnamed: D4.2 (A), R7.1
unnamed: D5.2 (A), R8.2, U4.16 (MOSI)
unnamed: J4.2, R6.2
unnamed: J4.3, R5.2
unnamed: J6.1, U4.15 (MISO)
unnamed: R1.2, U2.11 (PD5)
unnamed: R5.1, U4.21 (D+)
unnamed: R6.1, U4.20 (D-)
unnamed: R7.2, U4.11 (GPOUT7)
RST: J3.13, R1.1
SCK: D1.1 (K), J1.3, U2.19 (SCK/PB5), U3.2 (SCK)
TRBLED: J3.14, U2.14 (PB0)
TRBSW: J3.16, U2.12 (PD6)
UINT: U2.25 (PC2), U4.18 (INT)
~KBSS: U2.26 (PC3), U3.43 (CS)
~URES: D2.1 (K), U2.27 (PC4)
~USS: D3.1 (K), U2.28 (PC5)

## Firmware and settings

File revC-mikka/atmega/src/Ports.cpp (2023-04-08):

#include <avr/io.h>
#include <avr/interrupt.h>
#include <util/delay.h>
#include "SPI.h"
#include "UsbHostTask.h"
#include "Timers.h"

extern "C" int main(void);

int main(void) {
    PORTD &= ~_BV(PORTD5);                      // Hard reset Z state
    DDRD &= ~_BV(DDD5);                         // Hard reset Z state

    PORTD &= ~_BV(PORTD7);
    DDRD &= ~_BV(DDD7);                         // NMI Z state

    PORTD &= ~_BV(PORTD6);
    DDRD &= ~_BV(DDD6);                         // Turbo switch Z state

    DDRB &= ~_BV(DDB0);
    PORTB |= _BV(PORTB0);                      // Turbo LED in (PULLUP)

    DDRD |= _BV(DDD0);
    DDRD |= _BV(DDD1);
    DDRC |= _BV(DDC1);
    DDRC |= _BV(DDC0);

    SPI::Init();
    InitializeTimers();

    // Kempston Joystick outputs
    DDRB |= _BV(DDB1);
    DDRB |= _BV(DDB2);
    DDRD |= _BV(DDD2);
    DDRD |= _BV(DDD3);
    DDRD |= _BV(DDD4);

    _delay_ms(20);

    USBT::Init();

    sei();

    while(1) {
        USBT::Run();
    }
}

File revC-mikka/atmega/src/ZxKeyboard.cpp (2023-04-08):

#include "ZxKeyboard.h"
#include "HIDClassCommon.h"
#include "SPI.h"
#include "KeysList.h"
#include "KeyboardMapper.h"
#include "Joystick.h"

#define KBD_SHIFTS_SS_MASK 2
#define KBD_SHIFTS_CS_MASK 1

#define GET_ZX_KEY(x, y) (((x).val[((y)-1) >> 3] & (1 << (((y)-1) & 7))) != 0)
#define SET_ZX_KEY(x, y) x.val[((y)-1) >> 3] |= (1 << (((y)-1) & 7))
#define RESET_ZX_KEY(x, y) x.val[((y)-1) >> 3] &= ~(1 << (((y)-1) & 7))

void ZxKeyboard::UpdateZxKeys(const KeysList &ZxKeys) {
    struct ZxKeyMap {
        uint8_t val[6];
    };

    struct ZxKeyMap map{};

    memset(&map, 0, sizeof map);

    uint8_t &kempston_joystick = map.val[5];

    for (const auto &key: ZxKeys)
        if (key != 0)
            SET_ZX_KEY(map, key);

    bool new_ss = GET_ZX_KEY(map, ZXKey::SS);
    bool new_cs = GET_ZX_KEY(map, ZXKey::CS);

    uint16_t row0 = ((map.val[1] << 8) | (map.val[0])) & 0x3ff;
    uint16_t row1 = ((map.val[2] << 6) | (map.val[1] >> 2)) & 0x3ff;
    uint16_t row2 = ((map.val[3] << 4) | (map.val[2] >> 4)) & 0x3ff;
    uint16_t row3 = ((map.val[4] << 2) | (map.val[3] >> 6)) & 0x3ff;

    uint8_t presend = 0;

    if (new_ss && !WasSS) // SS pressed now. Pre-send it to avoid race in ZX keyboard polling
        presend |= KBD_SHIFTS_SS_MASK;

    if (new_cs && !WasCS) // CS pressed now. Pre-send it to avoid race in ZX keyboard polling
        presend |= KBD_SHIFTS_CS_MASK;

    if (presend != 0)
        SPI::WriteZxKeyboard(presend | (5 << 10));

    // Send whole bitmap to Zx Keyboard hub
    SPI::WriteZxKeyboard(row0 | (0 << 10));
    SPI::WriteZxKeyboard(row1 | (1 << 10));
    SPI::WriteZxKeyboard(row2 | (2 << 10));
    SPI::WriteZxKeyboard(row3 | (3 << 10));

    if (kempston_joystick & JOYSTICK_LEFT)
        PORTB |= _BV(PORTB2);
    else
        PORTB &= ~_BV(PORTB2);

    if (kempston_joystick & JOYSTICK_RIGHT)
        PORTB |= _BV(PORTB1);
    else
        PORTB &= ~_BV(PORTB1);

    if (kempston_joystick & JOYSTICK_UP)
        PORTD |= _BV(PORTD4);
    else
        PORTD &= ~_BV(PORTD4);

    if (kempston_joystick & JOYSTICK_DOWN)
        PORTD |= _BV(PORTD2);
    else
        PORTD &= ~_BV(PORTD2);

    // KJ Fire on ANY gamepad key
    if (kempston_joystick & JOYSTICK_FIRE)
        PORTD |= _BV(PORTD3);
    else
        PORTD &= ~_BV(PORTD3);

    WasSS = new_ss;
    WasCS = new_cs;
}

void ZxKeyboard::MapJoystickAndSend(KeysList &List) {
    List.clear();

    KeyboardMapper mapper(List, zxLayoutReference);

    mapper.MapKeyboard(IsLeftShiftPressed || IsRightShiftPressed, RusLayout, Keys);
}

void ZxKeyboard::Init() {
    UserSelectedLayoutInfo layoutInfo{};
    ConfigStorage >> layoutInfo;

    WasCS = false;
    WasSS = false;
    IsLeftShiftPressed = false;
    IsLeftCtrlPressed = false;
    IsLeftAltPressed = false;
    IsRightShiftPressed = false;
    IsRightCtrlPressed = false;
    IsRightAltPressed = false;
    IsWinPressed = false;
    JoyMapNum = layoutInfo.JoystickLayout;
    CapsLock = false;
    NumLock = false;

    SPI::WriteZxKeyboard(0 | (0 << 10));
    SPI::WriteZxKeyboard(0 | (1 << 10));
    SPI::WriteZxKeyboard(0 | (2 << 10));
    SPI::WriteZxKeyboard(0 | (3 << 10));

    SPI::WriteExt(0 | (3 << 8));

    RereadLayout(layoutInfo.KeyboardLayout);
}

void ZxKeyboard::RereadLayout(uint8_t LayoutNum) {
    LayoutNum = 0;
    if (LayoutNum > (sizeof LayoutReferences / sizeof LayoutReferences[0]))
        LayoutNum = 0;

    auto ref = &LayoutReferences[LayoutNum];
    auto iptr = (unsigned char *) ref;
    auto optr = (unsigned char *) &zxLayoutReference;
    for (uint8_t i = 0; i < sizeof zxLayoutReference; ++i)
        *(optr++) = pgm_read_byte(iptr++);
}
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

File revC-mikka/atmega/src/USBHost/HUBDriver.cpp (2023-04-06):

#include "HUBDriver.h"
#include "HIDClassCommon.h"
#include "usblib.h"
#include "SPI.h"
#include "MAX3421.h"
#include "DescriptorParser.h"
#include "Console.h"

using namespace USBH;

namespace USBT {
    extern HUBDriver hubDriver;
}

HUBDriver::HUBDriver() {
    uint8_t i = 1;
    for (auto &item: Ports) {
        //item.HubDevice = this;
        item.PortNum = i++;
        item.Flags.IsLowSpeedDevice = false;
    }
}

struct __attribute__((packed)) HubDescriptor {
    uint8_t bDescriptorLength;
    uint8_t bDescriptorType;
    uint8_t bNumberOfPorts;
    uint16_t wHubCharacteristics;
    uint8_t bPowerOnToPowerGood;
    uint8_t bHubControlCurrent;
    uint8_t bRemoveAndPowerMask[64];
};

struct PortStatus {
    uint8_t PortConnection: 1;
    uint8_t PortEnabled: 1;
    uint8_t PortSuspend: 1;
    uint8_t PortOvercurrent: 1;
    uint8_t PortReset: 1;
    uint8_t Reserved: 3;
    uint8_t PortPower: 1;
    uint8_t PortLowSpeed: 1;
    uint8_t PortHighSpeed: 1;
    uint8_t PortTest: 1;
    uint8_t PortIndicator: 1;
};

task<bool>
HUBDriver::Analyze(USBTarget &Device, uint8_t DeviceClass, const USBH::DescriptorParser &Descriptor) {
    if (UsbAddress != 0)
        co_return false;

    auto Interface = Descriptor.Interface;
    auto EndPoint = Descriptor.EndPointIn;

    if (Interface == nullptr || EndPoint == nullptr)
        co_return false;

    if (DeviceClass == 0)
        DeviceClass = Interface->bInterfaceClass;

    if (DeviceClass != HID_CSCP_HubClass)
        co_return false;

    Endpoint = EndPoint->bEndpointAddress & 0xf;
    UsbAddress = Device.UsbAddress;
    Flags.IsLowSpeedDevice = Device.Flags.IsLowSpeedDevice;

    co_await SetConfiguration(Descriptor.Configuration->bConfigurationValue);
}

task<void> HUBDriver::Probe() {
    if (UsbAddress == 0 || Flags.IsProbed)
        co_return;

    Flags.IsProbed = true;

    auto req = USB_Request_Header_t{
            .bmRequestType = 0b10100000,
            .bRequest      = USB_REQUEST_GET_DESCRIPTOR,
            .wValue        = 0x29 << 8,
            .wIndex        = 0,
            .wLength       = 8
    };

    uint8_t buf[10];
    auto desc = (HubDescriptor *) co_await ControlRead(buf, req, 8, *this);

    if (desc == nullptr)
        co_return;

    portsNumber = desc->bNumberOfPorts;

    // Опрос всех портов
    for (uint8_t i = 0; i < portsNumber; ++i) {
        uint16_t portmask = 1 << i;

        // SET PORT_POWER
        req = USB_Request_Header_t
                {
                        .bmRequestType = (REQDIR_HOSTTODEVICE | REQTYPE_CLASS | REQREC_INTERFACE |
                                          REQREC_ENDPOINT), // 0b00100011
                        .bRequest      = REQ_SetFeature,
                        .wValue        = 8,
                        .wIndex        = static_cast<uint16_t>(i + 1),
                        .wLength       = 0
                };

        co_await Control(req, *this);
        co_await USBH::Delay(50);

        // SET PORT_RESET
        req = {
                .bmRequestType = (REQDIR_HOSTTODEVICE | REQTYPE_CLASS | REQREC_INTERFACE |
                                  REQREC_ENDPOINT), // 0b00100011
                .bRequest      = REQ_SetFeature,
                .wValue        = 4,
                .wIndex        = static_cast<uint16_t>(i + 1),
                .wLength       = 0
        };

        co_await Control(req, *this);
        co_await USBH::Delay(50);

        req = {
                .bmRequestType = (REQDIR_DEVICETOHOST | REQTYPE_CLASS | REQREC_INTERFACE |
                                  REQREC_ENDPOINT), // 0b10100011
                .bRequest      = USB_REQUEST_GET_STATUS,
                .wValue        = 0,
                .wIndex        = static_cast<uint16_t>(i + 1),
                .wLength       = 4
        };

        auto status = (PortStatus *) co_await ControlRead(buf, req, 4, *this);

        if (status->PortConnection == 0)
            continue;

        CON << PSTR("HUB @") << DEC(UsbAddress) << PSTR(": ");

        if (status->PortLowSpeed)
            CON << PSTR("Low");
        else
            CON << PSTR("High");

        CON << PSTR(" speed device found at port ") << DEC(i) << endl();

        portsmask |= portmask;

        auto &p = Ports[i];

        p.Flags.IsLowSpeedDevice = status->PortLowSpeed;
        p.UsbAddress = 0;

        co_await USBH::InitializeNewDevice(p);
    }

    co_return;
}


task<bool> HUBDriver::Poll() {
    // Если состояние любого из портов изменилось - сброс стека
    for (uint8_t i = 0; i < portsNumber; ++i) {
        auto req = USB_Request_Header_t{
                .bmRequestType = (REQDIR_DEVICETOHOST | REQTYPE_CLASS | REQREC_INTERFACE |
                                  REQREC_ENDPOINT), // 0b10100011
                .bRequest      = USB_REQUEST_GET_STATUS,
                .wValue        = 0,
                .wIndex        = static_cast<uint16_t>(i + 1),
                .wLength       = 4
        };

        uint8_t buf[8];
        auto status = (PortStatus *) co_await ControlRead(buf, req, 4, *this);

        if (status == nullptr)
            continue;

        if ((status->PortConnection != 0) != ((portsmask & (1 << i)) != 0))
            co_return false;
    }

    co_return true;
}

void HUBDriver::Reset() {
    UsbAddress = 0;
    Endpoint = 0;
    Flags.IsLowSpeedDevice = false;
    Flags.SndToggle = false;
    Flags.RcvToggle = false;
    Flags.IsProbed = false;
    portsNumber = 0;
    portsmask = 0;

    for (auto &item: Ports) {
        item.Flags.IsLowSpeedDevice = false;
        item.UsbAddress = 0;
    }
}

task<void> HubPortInfo::ResetPort() {
    auto addr = SPI::ReadUSB(PERADDR);
    auto mode = SPI::ReadUSB(MODE);

    auto req = USB_Request_Header_t{
            .bmRequestType = (REQDIR_HOSTTODEVICE | REQTYPE_CLASS | REQREC_INTERFACE |
                              REQREC_ENDPOINT), // 0b00100011
            .bRequest      = REQ_SetFeature,
            .wValue        = 4,
            .wIndex        = PortNum,
            .wLength       = 0
    };

    //co_await HUBDriver::Control(req, *HubDevice);
    co_await HUBDriver::Control(req, USBT::hubDriver);

    SPI::WriteUSB(PERADDR, addr);
    SPI::WriteUSB(MODE, mode);
}

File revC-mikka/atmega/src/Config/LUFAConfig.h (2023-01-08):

/*
             LUFA Library
     Copyright (C) Dean Camera, 2021.

  dean [at] fourwalledcubicle [dot] com
           www.lufa-lib.org
*/

/*
  Copyright 2021  Dean Camera (dean [at] fourwalledcubicle [dot] com)

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
  The author disclaims all warranties with regard to this
  software, including all implied warranties of merchantability
  and fitness.  In no event shall the author be liable for any
  special, indirect or consequential damages or any damages
  whatsoever resulting from loss of use, data or profits, whether
  in an action of contract, negligence or other tortious action,
  arising out of or in connection with the use or performance of
  this software.
*/

/** \file
 *  \brief LUFA Library Configuration Header File
 *
 *  This header file is used to configure LUFA's compile time options,
 *  as an alternative to the compile time constants supplied through
 *  a makefile.
 *
 *  For information on what each token does, refer to the LUFA
 *  manual section "Summary of Compile Tokens".
 */

#ifndef _LUFA_CONFIG_H_
#define _LUFA_CONFIG_H_

	#if (ARCH == ARCH_AVR8)

		/* Non-USB Related Configuration Tokens: */
//		#define DISABLE_TERMINAL_CODES

		/* USB Class Driver Related Tokens: */
//		#define HID_HOST_BOOT_PROTOCOL_ONLY
//		#define HID_STATETABLE_STACK_DEPTH       {Insert Value Here}
//		#define HID_USAGE_STACK_DEPTH            {Insert Value Here}
//		#define HID_MAX_COLLECTIONS              {Insert Value Here}
//		#define HID_MAX_REPORTITEMS              {Insert Value Here}
//		#define HID_MAX_REPORT_IDS               {Insert Value Here}
//		#define NO_CLASS_DRIVER_AUTOFLUSH

		/* General USB Driver Related Tokens: */
//		#define ORDERED_EP_CONFIG
		#define USE_STATIC_OPTIONS               (USB_DEVICE_OPT_FULLSPEED | USB_OPT_REG_ENABLED | USB_OPT_AUTO_PLL)
		#define USB_DEVICE_ONLY
//		#define USB_HOST_ONLY
//		#define USB_STREAM_TIMEOUT_MS            {Insert Value Here}
		#define NO_LIMITED_CONTROLLER_CONNECT
//		#define NO_SOF_EVENTS

		/* USB Device Mode Driver Related Tokens: */
//		#define USE_RAM_DESCRIPTORS
		#define USE_FLASH_DESCRIPTORS
//		#define USE_EEPROM_DESCRIPTORS
//		#define NO_INTERNAL_SERIAL
		#define FIXED_CONTROL_ENDPOINT_SIZE      8
//		#define DEVICE_STATE_AS_GPIOR            {Insert Value Here}
		#define FIXED_NUM_CONFIGURATIONS         1
//		#define CONTROL_ONLY_DEVICE
		#define INTERRUPT_CONTROL_ENDPOINT
//		#define NO_DEVICE_REMOTE_WAKEUP
//		#define NO_DEVICE_SELF_POWER

		/* USB Host Mode Driver Related Tokens: */
//		#define HOST_STATE_AS_GPIOR              {Insert Value Here}
//		#define USB_HOST_TIMEOUT_MS              {Insert Value Here}
//		#define HOST_DEVICE_SETTLE_DELAY_MS	     {Insert Value Here}
//		#define NO_AUTO_VBUS_MANAGEMENT
//		#define INVERTED_VBUS_ENABLE_LINE

	#elif (ARCH == ARCH_XMEGA)

		/* Non-USB Related Configuration Tokens: */
//		#define DISABLE_TERMINAL_CODES

		/* USB Class Driver Related Tokens: */
//		#define HID_HOST_BOOT_PROTOCOL_ONLY
//		#define HID_STATETABLE_STACK_DEPTH       {Insert Value Here}
//		#define HID_USAGE_STACK_DEPTH            {Insert Value Here}
//		#define HID_MAX_COLLECTIONS              {Insert Value Here}
//		#define HID_MAX_REPORTITEMS              {Insert Value Here}
//		#define HID_MAX_REPORT_IDS               {Insert Value Here}
//		#define NO_CLASS_DRIVER_AUTOFLUSH

		/* General USB Driver Related Tokens: */
		#define USE_STATIC_OPTIONS               (USB_DEVICE_OPT_FULLSPEED | USB_OPT_RC32MCLKSRC | USB_OPT_BUSEVENT_PRIHIGH)
//		#define USB_STREAM_TIMEOUT_MS            {Insert Value Here}
//		#define NO_LIMITED_CONTROLLER_CONNECT
//		#define NO_SOF_EVENTS

		/* USB Device Mode Driver Related Tokens: */
//		#define USE_RAM_DESCRIPTORS
		#define USE_FLASH_DESCRIPTORS
//		#define USE_EEPROM_DESCRIPTORS
//		#define NO_INTERNAL_SERIAL
		#define FIXED_CONTROL_ENDPOINT_SIZE      8
//		#define DEVICE_STATE_AS_GPIOR            {Insert Value Here}
		#define FIXED_NUM_CONFIGURATIONS         1
//		#define CONTROL_ONLY_DEVICE
		#define MAX_ENDPOINT_INDEX               6
//		#define NO_DEVICE_REMOTE_WAKEUP
//		#define NO_DEVICE_SELF_POWER

	#else

		#error Unsupported architecture for this LUFA configuration file.

	#endif
#endif

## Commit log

2022-07-30 Sources updated
    [card.kicad_pcb, card.kicad_sch]
2023-01-07 revC added
    [card.kicad_pcb, card.kicad_sch]
2023-01-07 revA moved
    [card.kicad_pcb, card.kicad_sch]
2023-01-09 Gerbers added
2023-01-10 Schematic added
2023-06-14 Документация для производства
2023-09-10 Добавлено ПО управляющего микроконтроллера
2023-09-10 Добавлена программа сервисного обслуживания
2023-09-14 Добавлены исходники платы
    [ExtCard.kicad_sch, card.kicad_pcb, card.kicad_sch]
2023-11-19 Обновлена программа сервисного обслуживания. Обновлено ПО управляющего микроконтроллера. Исправлены некоторые ошибки записи макроса.
2024-04-12 Добавлен INF драйвер CDC для Windows 7
